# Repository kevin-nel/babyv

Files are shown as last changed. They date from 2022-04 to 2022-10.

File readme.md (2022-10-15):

# babyv case

**THIS IS A WORK IN PROGRESS**

<!-- put the nicest photo here -->

I really loved the alice-inspired ortholinear layout by eyeohdesigns, but I also really loved the (now discontinued) rounded and thick bezeled 3d printed case of the prime-e by p3d.
This is my attempt to marry the 2 designs with some inspiration from the multipart flurples c13x qaz alice style keyboard.

<!-- change this path to match the actual github link
<script src="https://embed.github.com/view/3d/kevin-nel/babyvcase/master/case/case.stl"></script>
-->
## current issues after first test print

- [ ] no angle makes it difficult to type
- [ ] no holder for micro
- [ ] overall too tall 
- [ ] tolerances need to be taken into consideration for the pegs in the split case (the connection is very tight and required sanding to make it fit)
- [ ] doesn't need to be 2 pieces. top case section can be integrated with the plate portion.

## todo

- [x] fix issues with stabiliser in plate
- [x] add hole in case for promicro (scad)
- [x] add holes in inner-case and bottom for screws (scad)
- [x] finalise dimensions (MS 3D Builder)
- [x] round top in blender
- [x] split and add keys in tinkercad
- [x] setup print jobs (gcode)
- [ ] post process prints
- [ ] wire up the matrix (rgb underglow?)
- [ ] solder the micro controller (take note of pins used)
- [ ] firmware

## a short summary of the very long winded design process

Due to my stubbornness :ox: and unwilingness to learn how to use a real CAD package (like freeCAD or fusion360), my design workflow goes like this:

```mermaid
flowchart
    A[edited svgs from a <br> laser cut case generator] --> B[openscad script  <br> to make case files];
    B --> C[mesh editing in blender <br> for bevels and round curvy bits];
    C --> D[tinkercad <br> to splice the files for actual printing];
    D --> E[realise something isn't quite right <br> and needs to be changed in the original svg];
    E-->A;
```

### a slighly longer summary

1. used the [svgs that were in the casefiles folder of the eyeohdesigns babyv repo](https://github.com/joedinkle/eyeohdesigns/tree/main/keyboards/babyv/casefiles) as starting point and edited them so that I had separate files for holes, outline, switch holes, and a top cutout. A little bit of editing was also done to the svgs to move the holes around.
2. openscad script to generate the stls for a 4 part case (bottom, case-inner, plate, case-top)
3. stabilisers:
    - original plate svg did not fit my stabs so I used the ``keyboardlayout.json`` from the [vial qmk repo](https://github.com/vial-kb/vial-qmk/blob/vial/keyboards/eyeohdesigns/babyv/keymaps/vial/vial.json) and generated a new svg of the plate in [builder.swillkb](http://www.builder.swillkb.com/)
    - needed to [flip the stabiliser cutout](https://builder-docs.swillkb.com/features/) by adding ``_rs:180`` to the key in the ``kle.json``
    - after some more test prints it was found that the cherry stab cutout fit best but needed some more room for the stabiliser wire, this was achieved by subtracting 2 rectangular prisms to make more room.
4. bevels and fine touches were added to the case top in blender
5. sliced up the model and added slots and keys to make for a stronger connection
6. imported the model into prusaslicer and split it into the separate objects and printed.

### some images of the design process

design in openscad
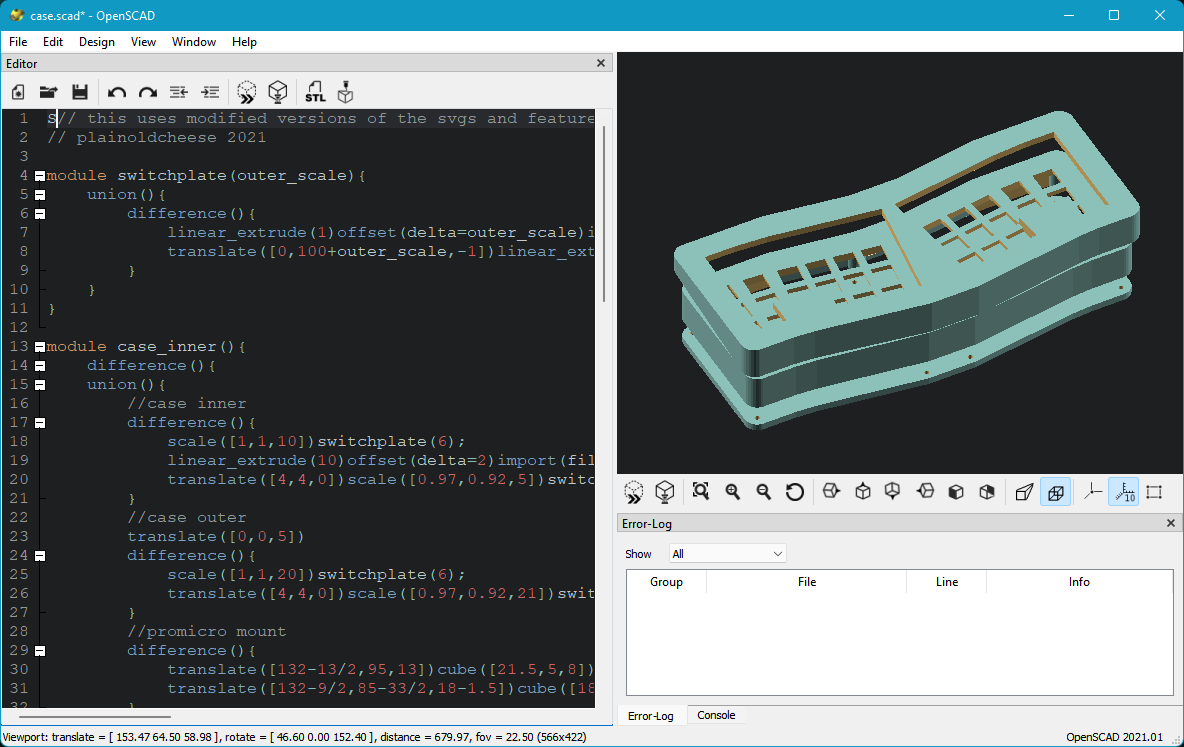
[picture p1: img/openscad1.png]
openscad

tweaking the mesh in blender (adding bevel on the top case and chamfering the usb hole)
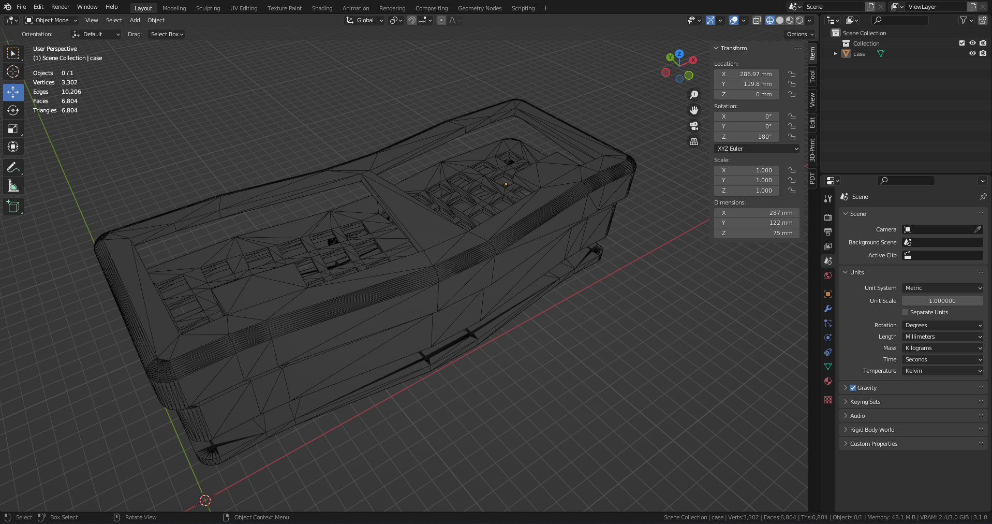
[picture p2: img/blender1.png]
blender

getting model ready to print in tinkercad
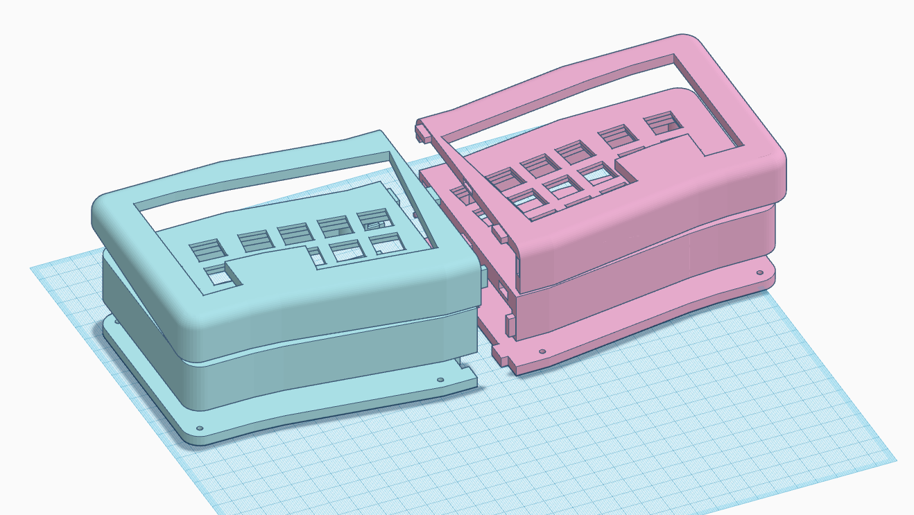
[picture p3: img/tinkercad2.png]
tinkercad keying

test prints to make sure the dimensions are right for the switches and stabilisers
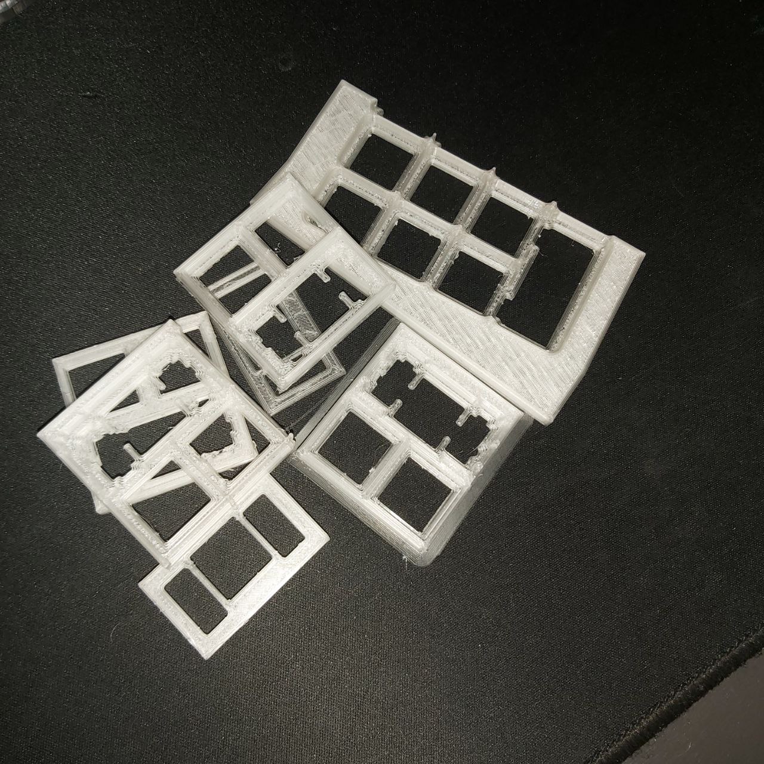
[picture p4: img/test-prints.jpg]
test prints of the plate

printing the case
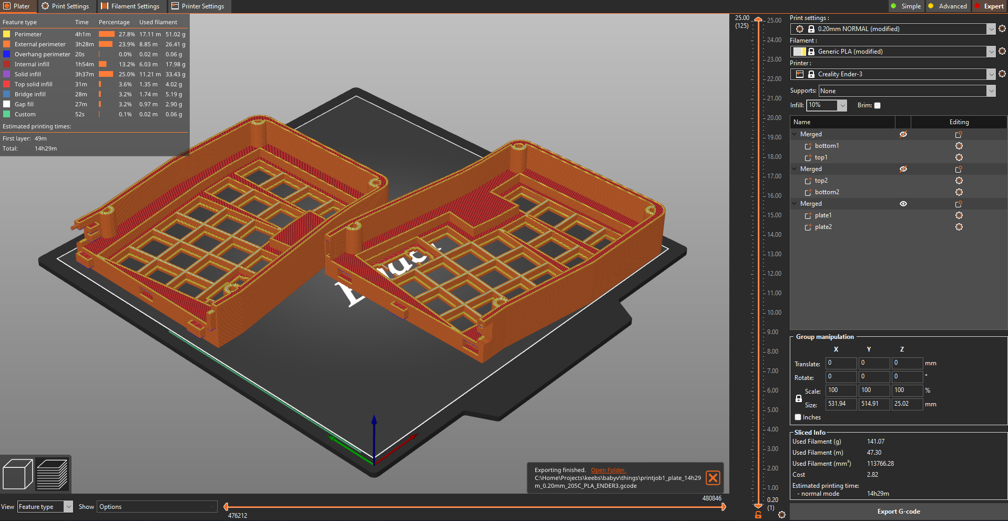
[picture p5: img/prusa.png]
prusa slicer job


## the build

### printing

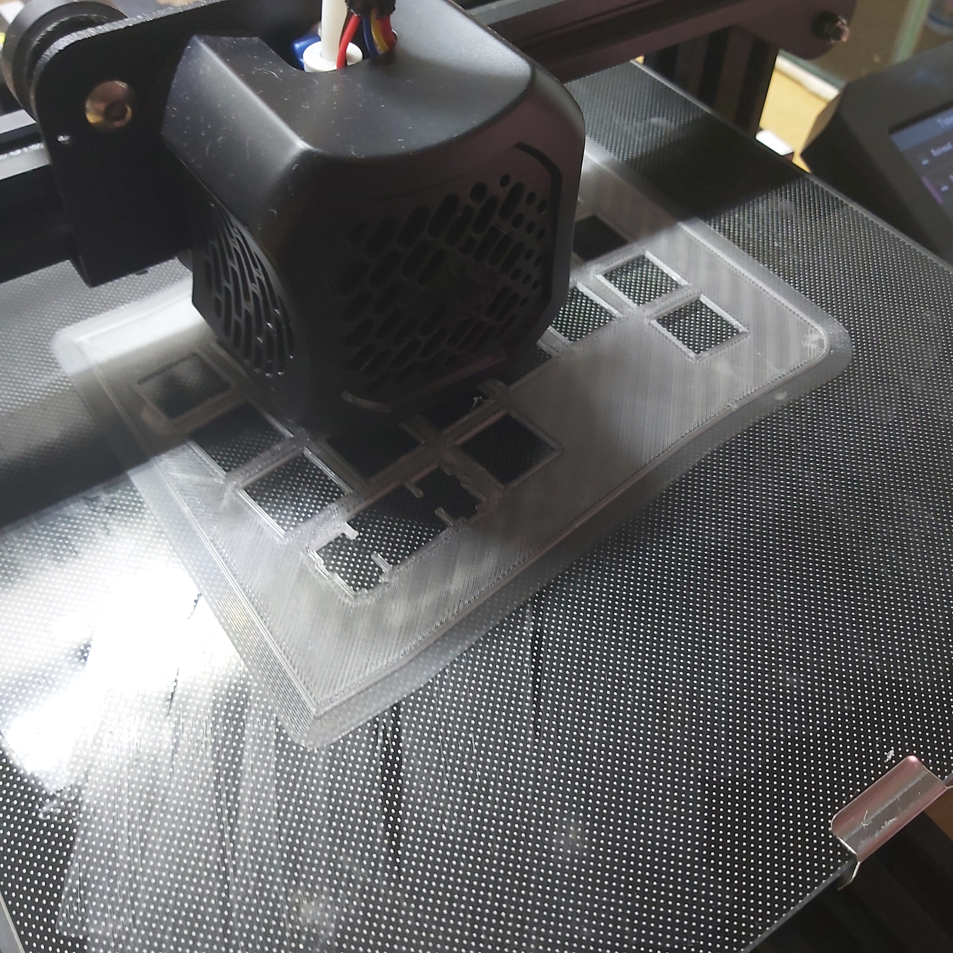
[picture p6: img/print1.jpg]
first layers looking good

trying to keep the print from coming loose
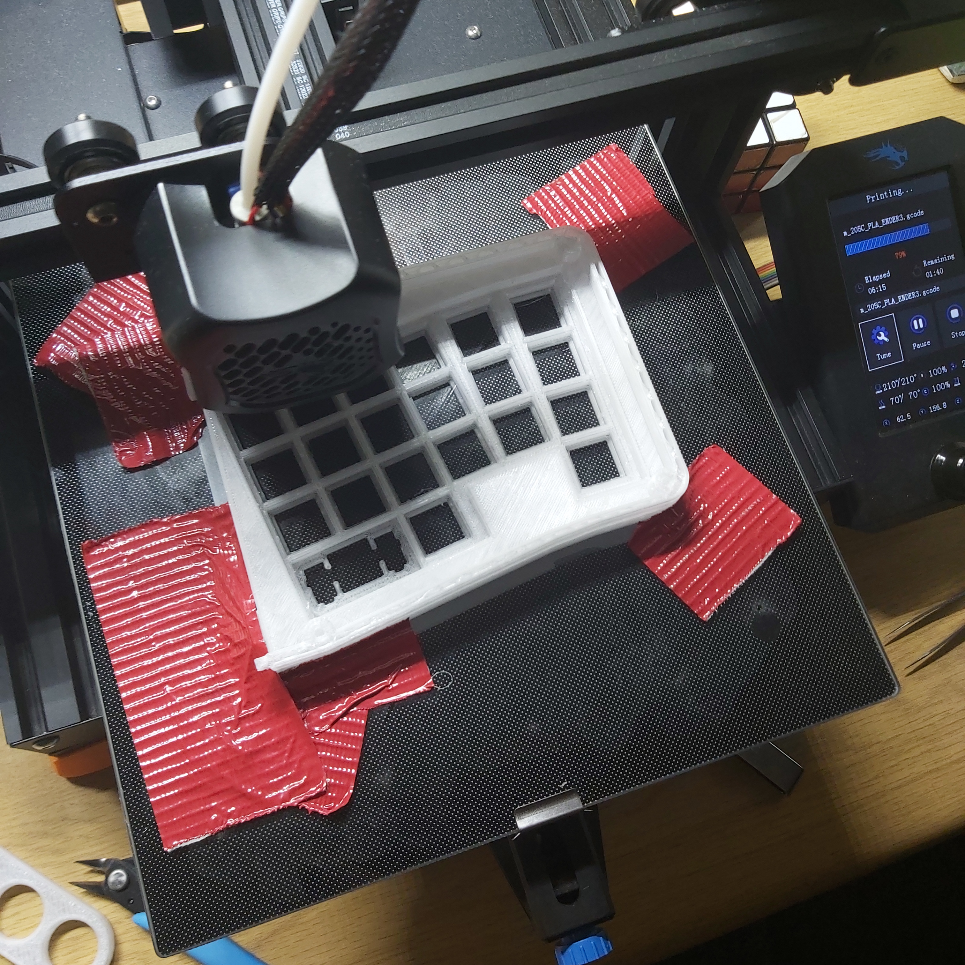
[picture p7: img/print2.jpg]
print started warping

that print was a fail (in more ways than 1)

### handwiring and firmware

this pro micro diagram proves helpful for every handwire

pro micro pin names


#### wiring

<!-- insert images of diode twisting, rows and columns and mcu all connected -->

#### firmware

I pretty much just copied the firmware from my previous builds and modified the keymap.c using the firmware available for the babyv on the vial qmk fork.

## final product

<!-- glory shots (also put the nicest photo at the top of the readme) -->

## useful links

- [gateron switch datasheet](https://objects.githubusercontent.com/github-production-repository-file-5c1aeb/50147694/6528571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)
- [cherry mx datasheet](https://media.digikey.com/PDF/Data%20Sheets/Cherry%20PDFs/MX%20Series.pdf)

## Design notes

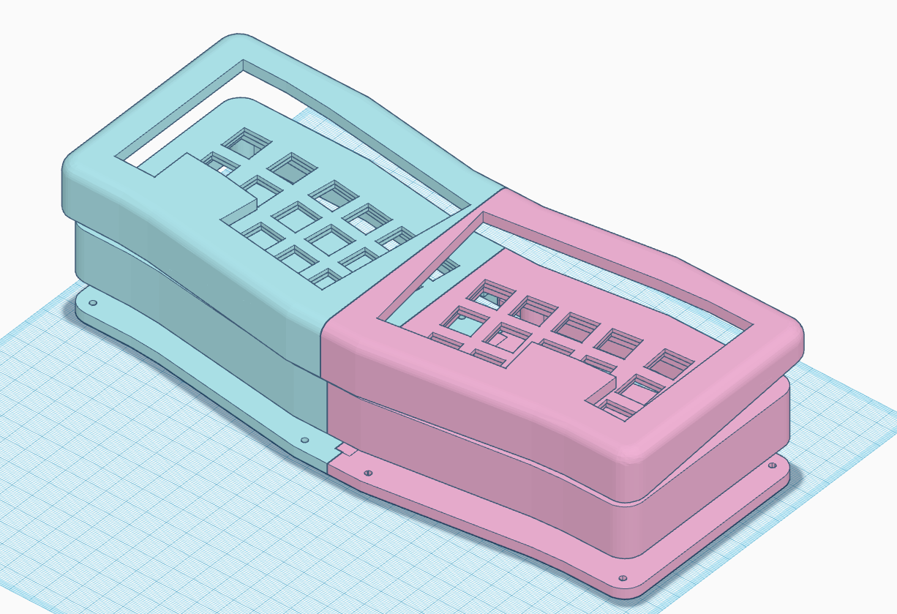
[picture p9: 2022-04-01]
img/tinkercad1.png

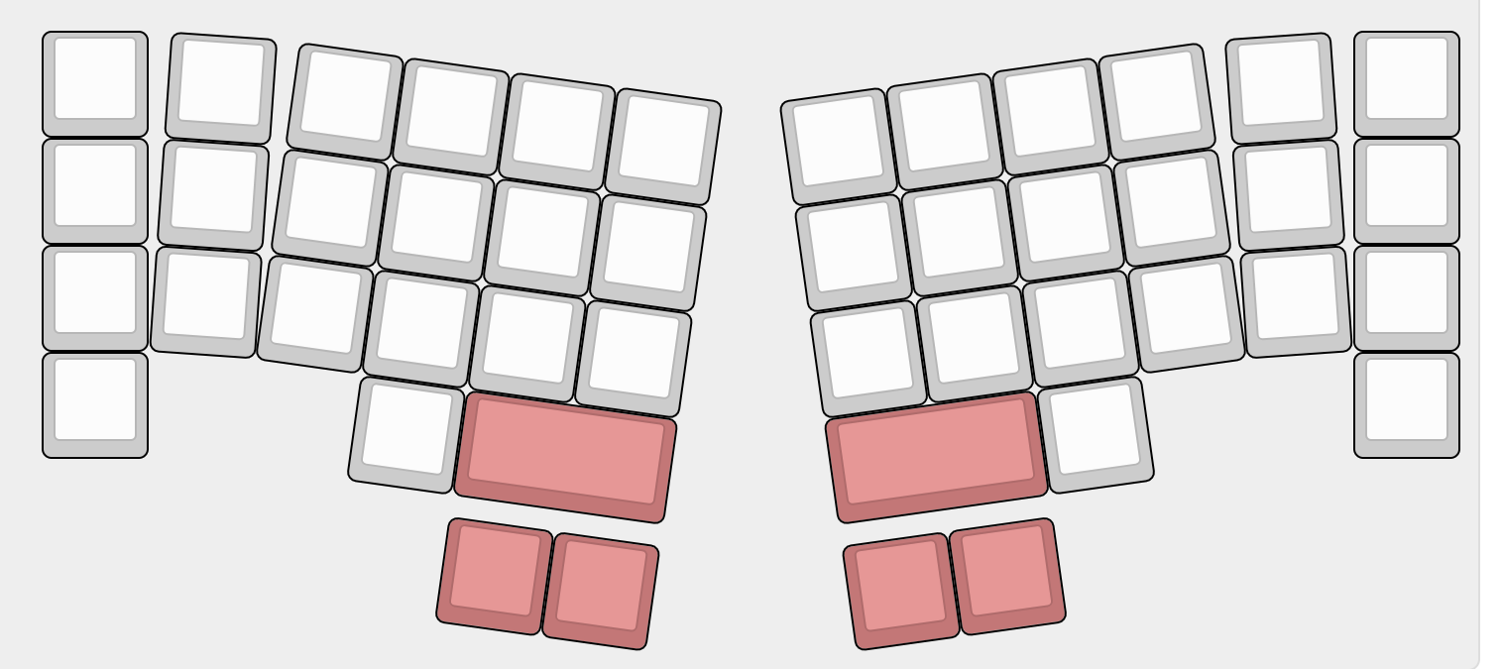
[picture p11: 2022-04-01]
img/GCurtgb.png

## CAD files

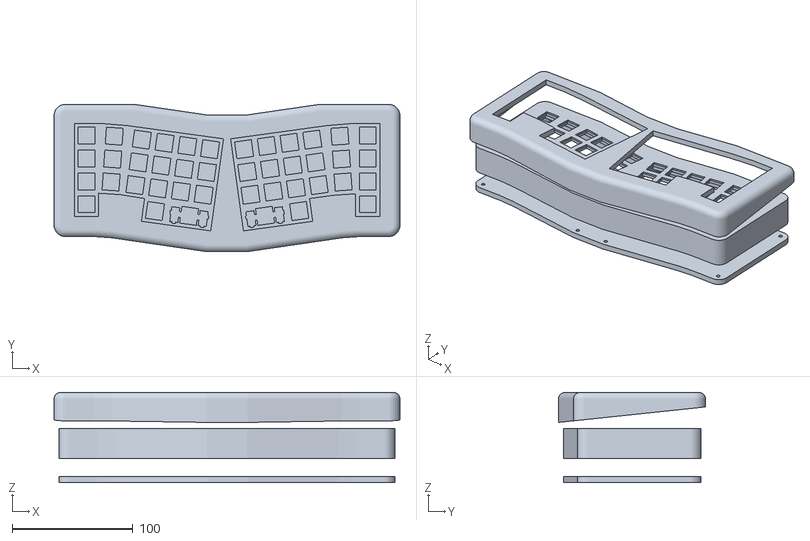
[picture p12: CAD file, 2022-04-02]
case/tweaks-repaired.obj
287.0 x 122.1 x 75.0

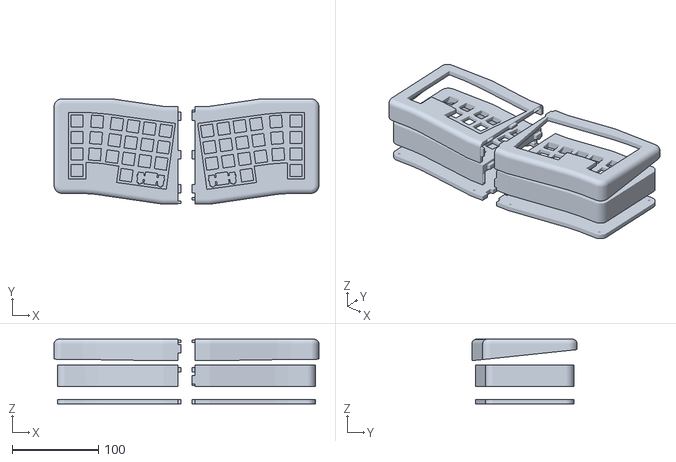
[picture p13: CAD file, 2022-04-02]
things/case_split.stl
307.0 x 122.1 x 75.0

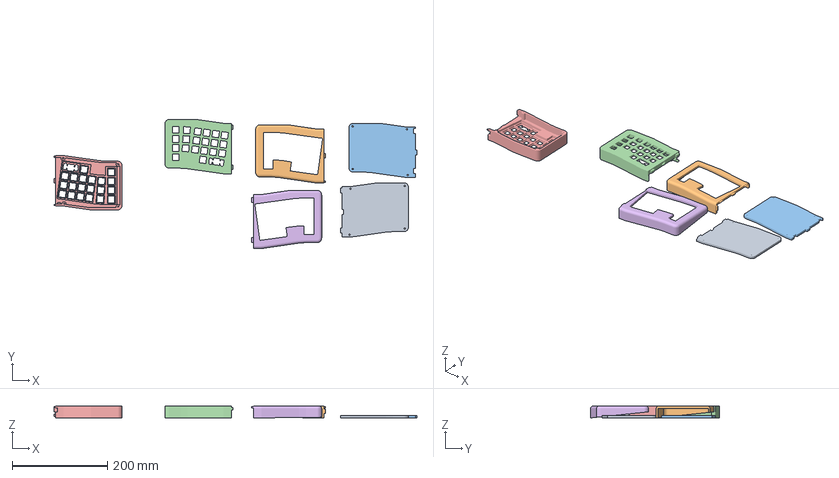
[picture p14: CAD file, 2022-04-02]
things/printjob_ender3v2/printjob.3mf
761.8 x 271.0 x 25.0 mm
plate-right
top-left
plate-left
case-left
case-right
top-right

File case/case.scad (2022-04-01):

S// this uses modified versions of the svgs and features a curved top and screw holes as well as a slot for pro micro.
// plainoldcheese 2021

module switchplate(outer_scale){
    union(){
        difference(){
            linear_extrude(1)offset(delta=outer_scale)import(file="svgs/SwitchPlate.svg",center = false);
            translate([0,100+outer_scale,-1])linear_extrude(3)offset(delta=outer_scale)import(file="svgs/SwitchPlate.svg",center = false);
        }
    }
}

module case_inner(){
    difference(){
    union(){
        //case inner
        difference(){
            scale([1,1,10])switchplate(6);
            linear_extrude(10)offset(delta=2)import(file="svgs/Top.svg",center = false);        
            translate([4,4,0])scale([0.97,0.92,5])switchplate(6);
        }
        //case outer
        translate([0,0,5])
        difference(){
            scale([1,1,20])switchplate(6);     
            translate([4,4,0])scale([0.97,0.92,21])switchplate(6);  
        }
        //promicro mount
        difference(){
            translate([132-13/2,95,13])cube([21.5,5,8]);
            translate([132-9/2,85-33/2,18-1.5])cube([18,33,1.5]);
        }
        //screw holes
        difference(){
            translate([0,0,5])linear_extrude(20)offset(delta=3)import(file="svgs/ScrewHoles.svg",center = false);
            translate([0,0,15])linear_extrude(10)offset(delta=0)import(file="svgs/ScrewHoles.svg",center = false);
            translate([0,100+6,-1])linear_extrude(50)offset(delta=6)import(file="svgs/SwitchPlate.svg",center = false);    } 
    }
    translate([132,90,8+5])cube([8,18,8]); //usb hole
    }
}
module plate(){
    union(){
        difference(){
            //plate
            translate([4,4,0])scale([0.97,0.92,5])switchplate(6);
            //holes
            union(){
                translate([4+0.68+0.05-0.0450000000,5,0])linear_extrude(5)import(file="svgs/SwitchHolesUpdated.svg",center = false);
                translate([4+0.68+0.05-0.0450000000,5,1.5])linear_extrude(5-1.5)offset(delta=1.4)import(file="svgs/SwitchHolesUpdated.svg",center = false);
            }
            // extra room for stabilisers to clip
            rotate([0,0,-8])translate([19*4+5+1,23+3-.5,1.5])cube([19*2-2,19.5,5]);
            rotate([0,0,8])translate([19*8-2+1,-11-1-.5,1.5])cube([19*2-2,19.5,5]);
        }
    }
}
module case_top(){    
    union(){
        translate([272,0,0])
        rotate([180,0,180])
        difference(){
            difference(){
                translate([-4,-4,0])scale([1.03,1.07,25])switchplate(6);
                translate([0,0,0])scale([1,1,20])switchplate(6);
                translate([0,0,20])linear_extrude(5)import(file="svgs/Top.svg",center = false); 
            }
            rotate([6,0,0])translate([-20,-20,-29.2])cube([315,150,30]);
        }
}
}

module bottom(){
    //bottom plate with holes for screws
    difference(){
        scale([1,1,5])switchplate(6);
        translate([0,0,-2.5])linear_extrude(10)offset(delta=0)import(file="svgs/ScrewHoles.svg",center = false);     
    }
}

// case generation

translate([7.5,114.5,45])rotate([180,0,0])
union(){
    //top
    translate([0,0,-5])case_top();
    
    //one piece case and plate
    union(){
        //switchplate
        translate([0,0,0])plate();
        //case inner
        translate([0,0,0])case_inner();
    }

    //bottom plate
    translate([0,0,40])bottom();
}

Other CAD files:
case/tweaks.stl
case/case.stl
case/case-old.scad
case/tweaks.blend

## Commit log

2022-04-01 init commit
    [case.scad, plate-test.stl, plate-test2.stl]
2022-04-01 add temp case preview
    [case.scad, case.stl]
2022-04-01 add holes for bottom plate
    [case.scad, case.stl]
2022-04-01 update to have plate and inner case be one piece
    [case-old.scad, case.scad, case.stl]
2022-04-01 final steps before printing
    [case-old.scad, case.obj, case.scad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]
2022-04-02 split print job
    [printjob.3mf]
2022-04-02 fix plate thickness (first print failed)
    I used an old file when splitting in tinkercad :tired_face:
    [case.obj, case_split.stl, printjob.3mf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]
